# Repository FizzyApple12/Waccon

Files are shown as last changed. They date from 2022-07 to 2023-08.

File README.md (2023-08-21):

# Waccon

This repo is right now still a work in progress, nothing has been finalized and things will probably be broken, stay tuned as things are finalized though!

Simplified CAD Screenshot

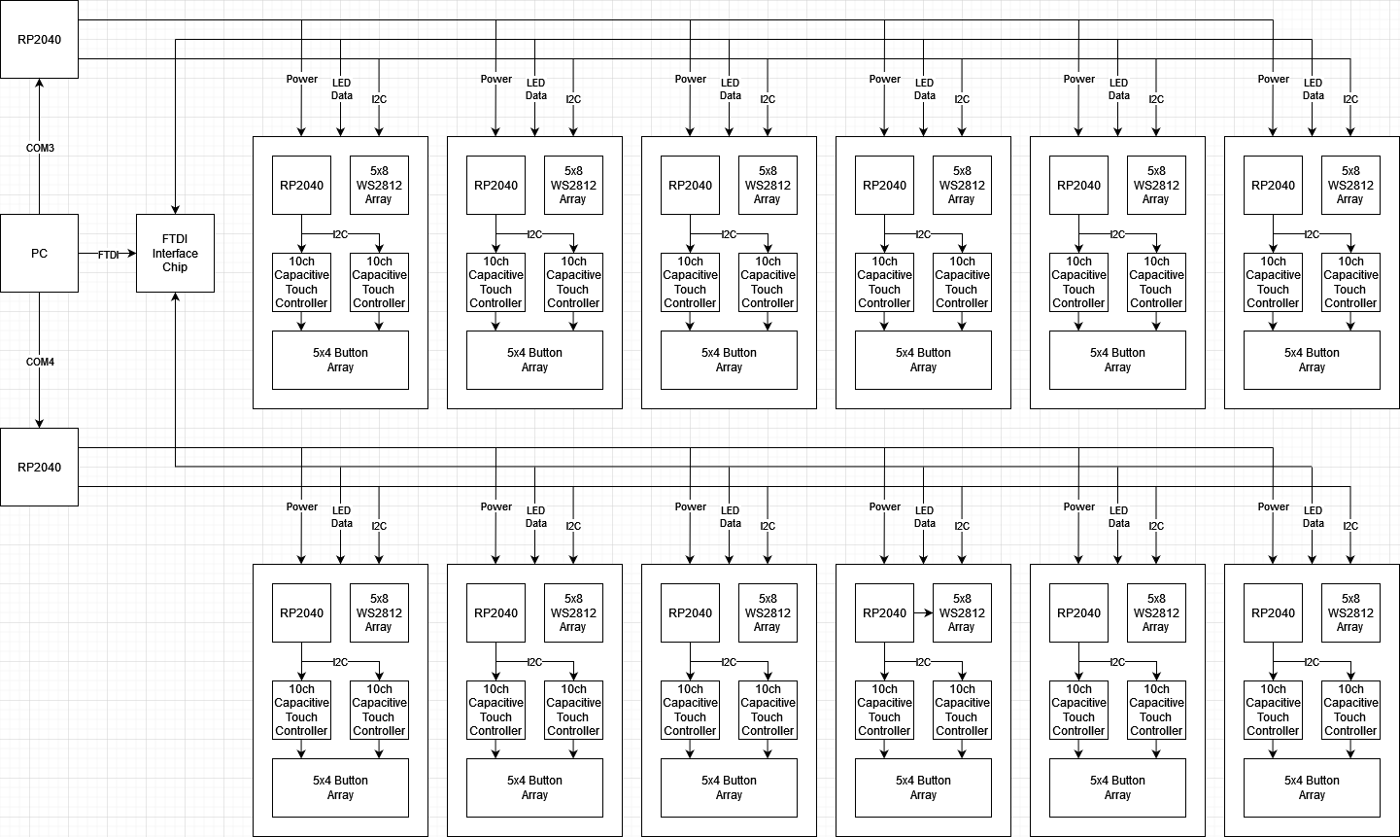
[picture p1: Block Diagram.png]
Controller Block Diagram


If you'd like to test out the current firmware on your own hardware, there are 2 github actions scripts for the Touch Panel firmware and the Protocol Translator firmware

The 6 Touch Panel firmware builds correspond to which position you want the Touch Panel to be in (1 being top, 6 being bottom)

The 4 Protocol Translator firmware builds correspond to if the translator is controlling the left or right of the controller and if you want to mirror Touch Panel 1's inputs to all 6 Touch Panels

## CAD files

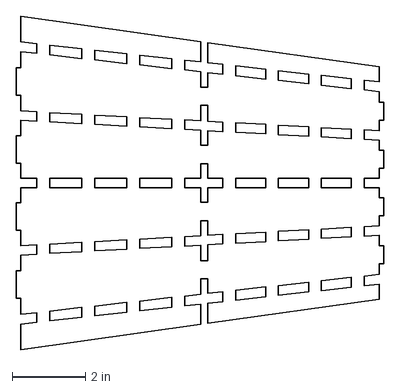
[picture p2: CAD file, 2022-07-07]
WaccaTouchPanel-pcb/pcbBorder.dxf
10.0 x 9.10 in

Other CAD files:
Wacca Controller/Full Controller.iam
Wacca Controller/Half Ring/Half Ring.iam
Wacca Controller/Touch Segment/Back Plate.ipt
Wacca Controller/Touch Segment/Center Plate.ipt
Wacca Controller/Touch Segment/Front Plate.ipt
Wacca Controller/Touch Segment/Inner Bracket.ipt
Wacca Controller/Touch Segment/Joiner.ipt
Wacca Controller/Touch Segment/PCB.ipt
Wacca Controller/Touch Segment/SidePlate.ipt
Wacca Controller/Touch Segment/Touch Fifth.ipt
Wacca Controller/Touch Segment/Touch Segment.iam

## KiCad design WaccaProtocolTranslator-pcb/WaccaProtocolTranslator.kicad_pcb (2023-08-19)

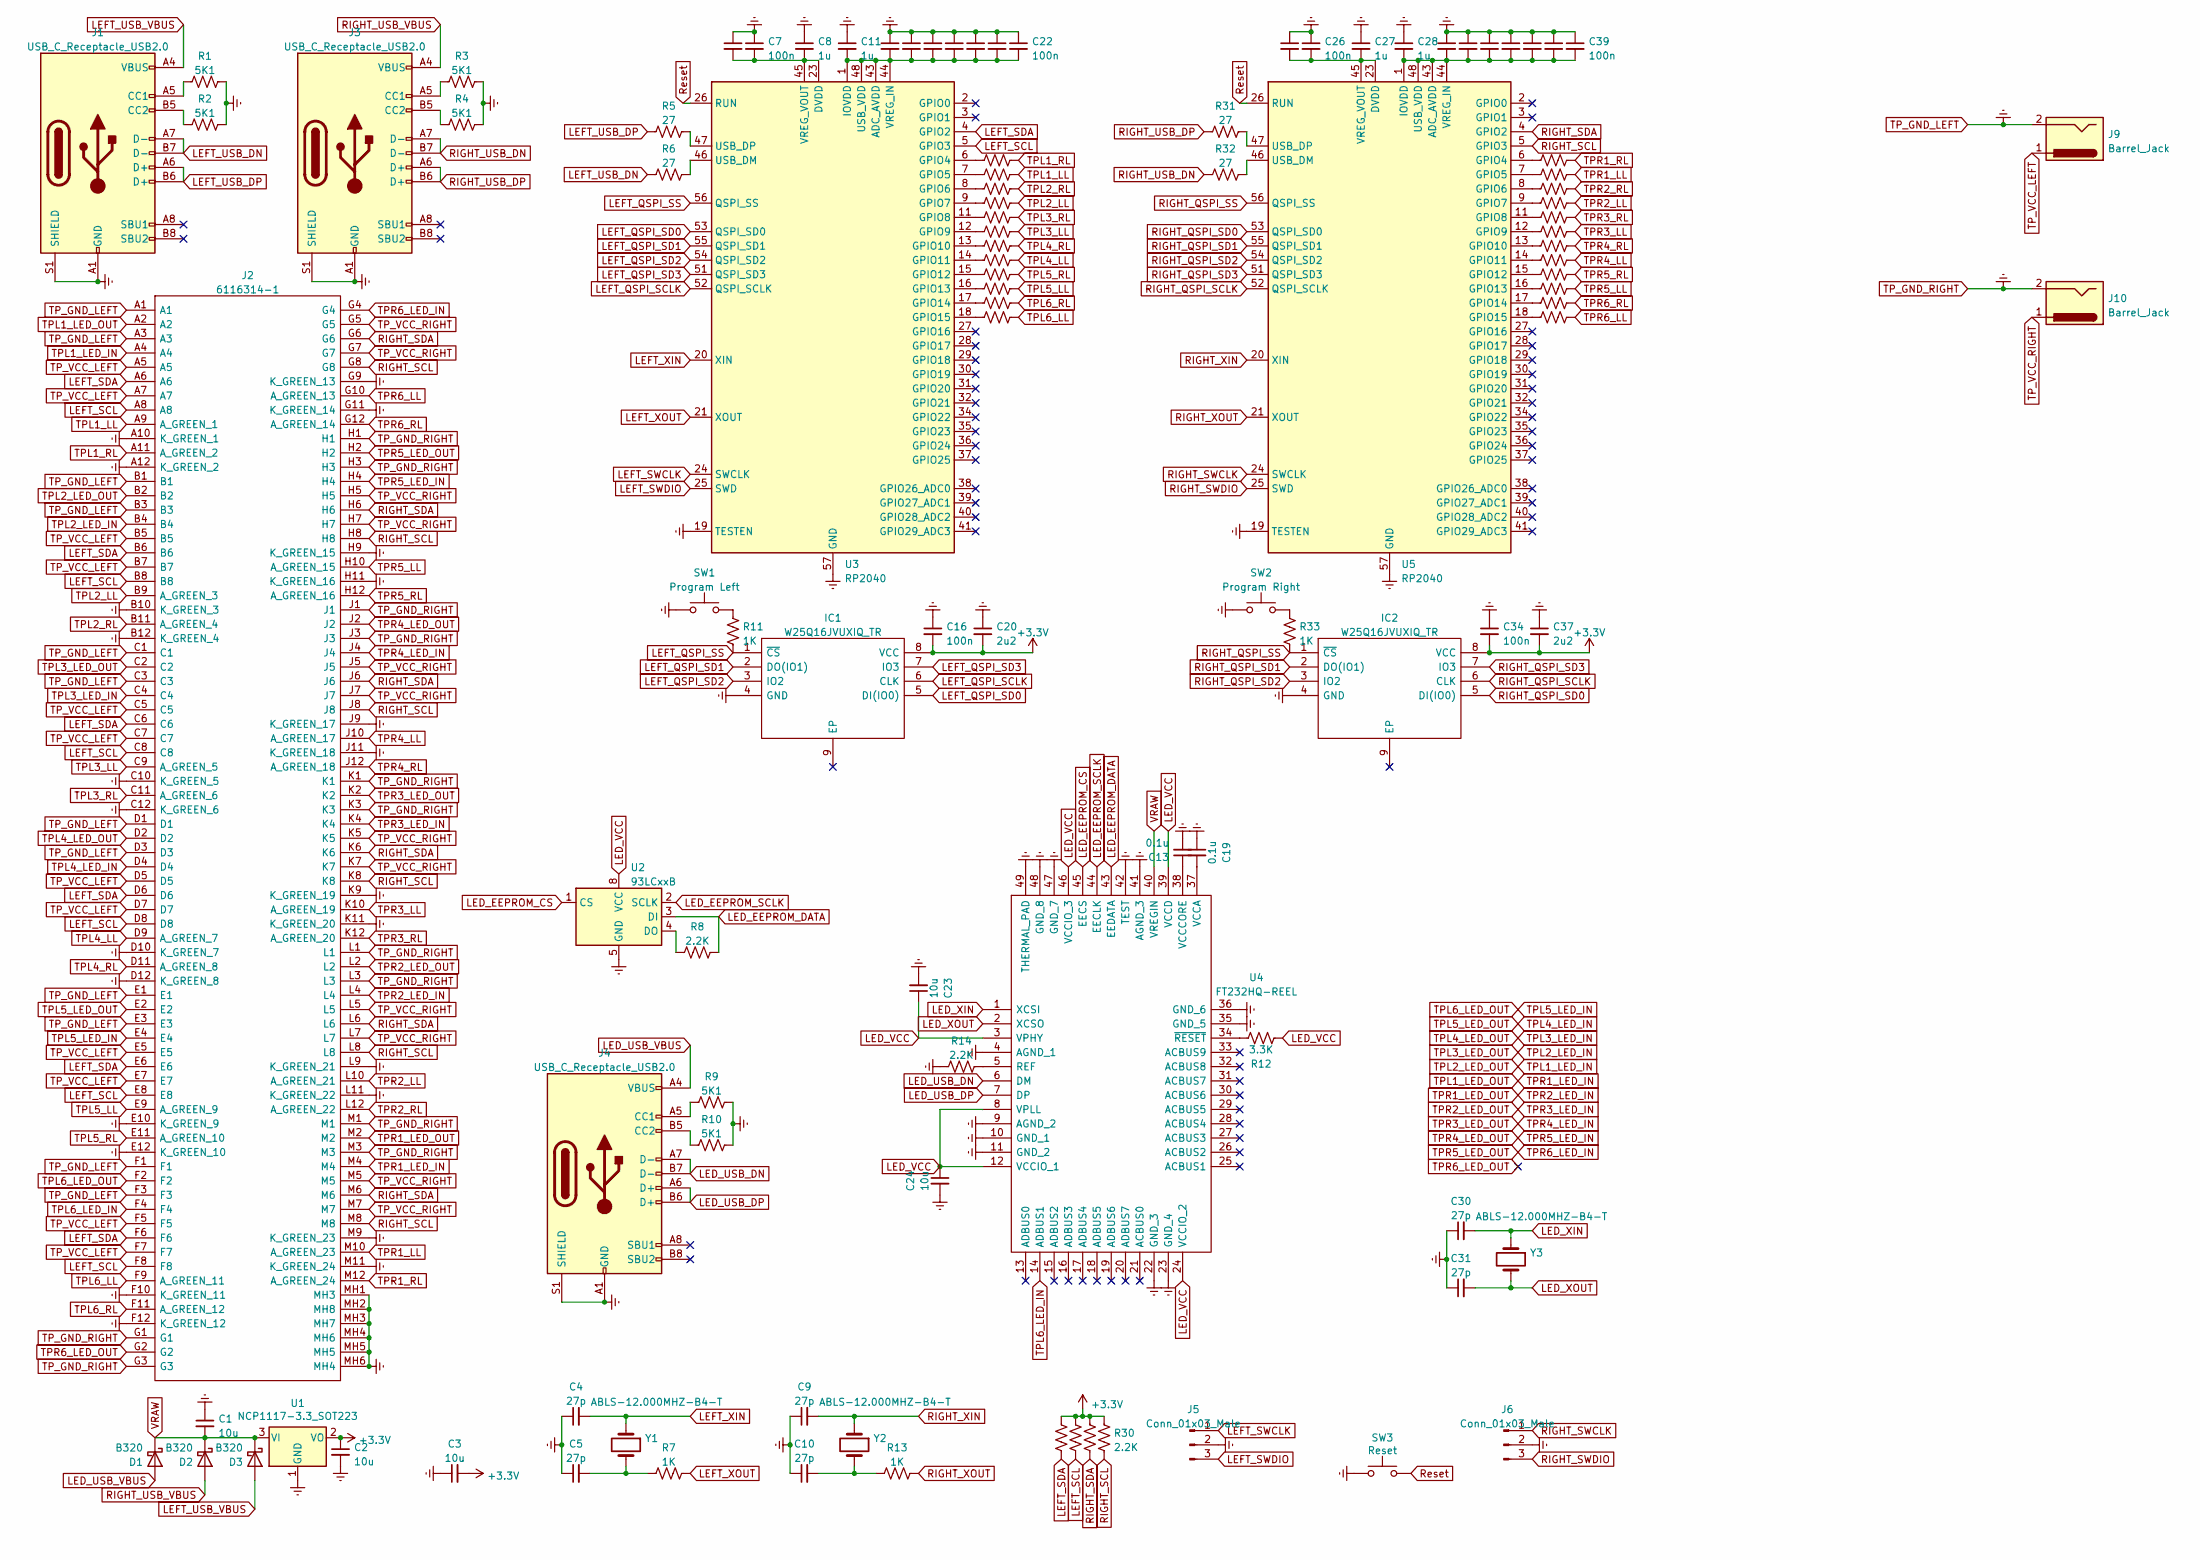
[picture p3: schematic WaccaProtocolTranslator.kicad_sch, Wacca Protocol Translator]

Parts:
C1, C2, C3, C23, C24: 10u; C_0402_1005Metric
C4, C5, C9, C10, C30, C31: 27p; C_0402_1005Metric
C6, C7, C12, C14, C15, C16, C17, C18, C21, C22, C25, C26, C29, C32, C33, C34, C35, C36, C38, C39: 100n; C_0402_1005Metric
C8, C11, C27, C28: 1u; C_0402_1005Metric
C13, C19: 0.1u; C_0402_1005Metric
C20, C37: 2u2; C_0402_1005Metric
D1, D2, D3: B320; D_SMC
IC1, IC2: W25Q16JVUXIQ_TR; SON50P300X200X60-9N; Manufacturer_Part_Number W25Q16JVUXIQ TR; Mouser Part Number 454-W25Q16JVUXIQTR
J1, J3, J4: USB_C_Receptacle_USB2.0; USB_C_Receptacle_Amphenol_12401548E4-2A
J2: 6116314-1; 61163141; Mouser Part Number 571-6116314-1
J5, J6: Conn_01x03_Male; PinHeader_1x03_P2.54mm_Vertical
J9, J10: Barrel_Jack; BarrelJack_CUI_PJ-063AH_Horizontal
R1, R2, R3, R4, R9, R10: 5K1; R_0402_1005Metric
R5, R6, R31, R32: 27; R_0402_1005Metric
R7, R11, R13, R33: 1K; R_0402_1005Metric
R8, R14, R27, R28, R29, R30: 2.2K; R_0402_1005Metric
R12: 3.3K; R_0402_1005Metric
R15, R16, R17, R18, R19, R20, R21, R22, R23, R24, R25, R26, R34, R35, R36, R37, R38, R39, R40, R41, R42, R43, R44, R45: 150; R_0402_1005Metric
SW1: Program Left; SW_SPST_B3U-1000P
SW2: Program Right; SW_SPST_B3U-1000P
SW3: Reset; SW_SPST_B3U-1000P
U1: NCP1117-3.3_SOT223; SOT-223-3_TabPin2
U2: 93LCxxB; SOP65P490X110-8N
U3, U5: RP2040; QFN-56-1EP_7x7mm_P0.4mm_EP3.2x3.2mm
U4: FT232HQ-REEL; QFN50P800X800X100-49N-D; Mouser Part Number 895-FT232HQ-REEL
Y1, Y2, Y3: ABLS-12.000MHZ-B4-T; Crystal_HC49-4H_Vertical

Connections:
+3.3V: C2.1, C3.2, C16.2, C20.2, C34.2, C37.2, IC1.8 (VCC), IC2.8 (VCC), R27.2, R28.2, R29.2, R30.2, U1.2 (VO)
LED_EEPROM_CS: U2.1 (CS), U4.45 (EECS)
LED_EEPROM_DATA: R8.2, U2.3 (DI), U4.43 (EEDATA)
LED_EEPROM_SCLK: U2.2 (SCLK), U4.44 (EECLK)
LED_USB_DN: J4.A7 (D-), J4.B7 (D-), U4.6 (DM)
LED_USB_DP: J4.A6 (D+), J4.B6 (D+), U4.7 (DP)
LED_USB_VBUS: D1.2 (A), J4.A4 (VBUS), J4.A9 (VBUS), J4.B4 (VBUS), J4.B9 (VBUS)
LED_VCC: C23.1, C24.1, R12.1, U2.8 (VCC), U4.3 (VPHY), U4.8 (VPLL), U4.12 (VCCIO_1), U4.24 (VCCIO_2), U4.39 (VCCD), U4.46 (VCCIO_3)
LED_XIN: C30.2, U4.1 (XCSI), Y3.1
LED_XOUT: C31.2, U4.2 (XCSO), Y3.2
LEFT_QSPI_SCLK: IC1.6 (CLK), U3.52 (QSPI_SCLK)
LEFT_QSPI_SD0: IC1.5 (DI(IO0)), U3.53 (QSPI_SD0)
LEFT_QSPI_SD1: IC1.2 (DO(IO1)), U3.55 (QSPI_SD1)
LEFT_QSPI_SD2: IC1.3 (IO2), U3.54 (QSPI_SD2)
LEFT_QSPI_SD3: IC1.7 (IO3), U3.51 (QSPI_SD3)
LEFT_QSPI_SS: IC1.1 (~CS), R11.2, U3.56 (QSPI_SS)
LEFT_SCL: J2.A8, J2.B8, J2.C8, J2.D8, J2.E8, J2.F8, R28.1, U3.5 (GPIO3)
LEFT_SDA: J2.A6, J2.B6, J2.C6, J2.D6, J2.E6, J2.F6, R27.1, U3.4 (GPIO2)
LEFT_SWCLK: J5.1, U3.24 (SWCLK)
LEFT_SWDIO: J5.3, U3.25 (SWD)
LEFT_USB_DN: J1.A7 (D-), J1.B7 (D-), R6.1
LEFT_USB_DP: J1.A6 (D+), J1.B6 (D+), R5.1
LEFT_USB_VBUS: D3.2 (A), J1.A4 (VBUS), J1.A9 (VBUS), J1.B4 (VBUS), J1.B9 (VBUS)
LEFT_XIN: C4.2, U3.20 (XIN), Y1.1
LEFT_XOUT: R7.2, U3.21 (XOUT)
unnamed: C5.2, R7.1, Y1.2
unnamed: C10.2, R13.1, Y2.2
unnamed: J1.A5 (CC1), R1.1
unnamed: J1.B5 (CC2), R2.1
unnamed: J3.A5 (CC1), R3.1
unnamed: J3.B5 (CC2), R4.1
unnamed: J4.A5 (CC1), R9.1
unnamed: J4.B5 (CC2), R10.1
unnamed: R11.1, SW1.2
unnamed: R33.1, SW2.2
unnamed: R8.1, U2.4 (DO)
unnamed: C11.2, C12.2, C14.2, C15.2, C17.2, C18.2, C21.2, C22.2, U3.1 (IOVDD), U3.10 (IOVDD), U3.22 (IOVDD), U3.33 (IOVDD), U3.42 (IOVDD), U3.43 (ADC_AVDD), U3.44 (VREG_IN), U3.48 (USB_VDD), U3.49 (IOVDD)
unnamed: R16.1, U3.6 (GPIO4)
unnamed: R15.1, U3.7 (GPIO5)
unnamed: R18.1, U3.8 (GPIO6)
unnamed: R17.1, U3.9 (GPIO7)
unnamed: R20.1, U3.11 (GPIO8)
unnamed: R19.1, U3.12 (GPIO9)
unnamed: R22.1, U3.13 (GPIO10)
unnamed: R21.1, U3.14 (GPIO11)
unnamed: R24.1, U3.15 (GPIO12)
unnamed: R23.1, U3.16 (GPIO13)
unnamed: R26.1, U3.17 (GPIO14)
unnamed: R25.1, U3.18 (GPIO15)
unnamed: R6.2, U3.46 (USB_DM)
unnamed: R5.2, U3.47 (USB_DP)
unnamed: C6.2, C7.2, C8.2, U3.23 (DVDD), U3.45 (VREG_VOUT), U3.50 (DVDD)
unnamed: R14.2, U4.5 (REF)
unnamed: C19.2, U4.37 (VCCA)
unnamed: C13.1, U4.38 (VCCCORE)
unnamed: R12.2, U4.34 (~RESET)
unnamed: C28.2, C29.2, C32.2, C33.2, C35.2, C36.2, C38.2, C39.2, U5.1 (IOVDD), U5.10 (IOVDD), U5.22 (IOVDD), U5.33 (IOVDD), U5.42 (IOVDD), U5.43 (ADC_AVDD), U5.44 (VREG_IN), U5.48 (USB_VDD), U5.49 (IOVDD)
unnamed: R35.1, U5.6 (GPIO4)
unnamed: R34.1, U5.7 (GPIO5)
unnamed: R37.1, U5.8 (GPIO6)
unnamed: R36.1, U5.9 (GPIO7)
unnamed: R39.1, U5.11 (GPIO8)
unnamed: R38.1, U5.12 (GPIO9)
unnamed: R41.1, U5.13 (GPIO10)
unnamed: R40.1, U5.14 (GPIO11)
unnamed: R43.1, U5.15 (GPIO12)
unnamed: R42.1, U5.16 (GPIO13)
unnamed: R45.1, U5.17 (GPIO14)
unnamed: R44.1, U5.18 (GPIO15)
unnamed: R32.2, U5.46 (USB_DM)
unnamed: R31.2, U5.47 (USB_DP)
unnamed: C25.2, C26.2, C27.2, U5.23 (DVDD), U5.45 (VREG_VOUT), U5.50 (DVDD)
RIGHT_QSPI_SCLK: IC2.6 (CLK), U5.52 (QSPI_SCLK)
RIGHT_QSPI_SD0: IC2.5 (DI(IO0)), U5.53 (QSPI_SD0)
RIGHT_QSPI_SD1: IC2.2 (DO(IO1)), U5.55 (QSPI_SD1)
RIGHT_QSPI_SD2: IC2.3 (IO2), U5.54 (QSPI_SD2)
RIGHT_QSPI_SD3: IC2.7 (IO3), U5.51 (QSPI_SD3)
RIGHT_QSPI_SS: IC2.1 (~CS), R33.2, U5.56 (QSPI_SS)
RIGHT_SCL: J2.G8, J2.H8, J2.J8, J2.K8, J2.L8, J2.M8, R30.1, U5.5 (GPIO3)
RIGHT_SDA: J2.G6, J2.H6, J2.J6, J2.K6, J2.L6, J2.M6, R29.1, U5.4 (GPIO2)
RIGHT_SWCLK: J6.1, U5.24 (SWCLK)
RIGHT_SWDIO: J6.3, U5.25 (SWD)
RIGHT_USB_DN: J3.A7 (D-), J3.B7 (D-), R32.1
RIGHT_USB_DP: J3.A6 (D+), J3.B6 (D+), R31.1
RIGHT_USB_VBUS: D2.2 (A), J3.A4 (VBUS), J3.A9 (VBUS), J3.B4 (VBUS), J3.B9 (VBUS)
RIGHT_XIN: C9.2, U5.20 (XIN), Y2.1
RIGHT_XOUT: R13.2, U5.21 (XOUT)
Reset: SW3.2, U3.26 (RUN), U5.26 (RUN)
TPL1_LED_IN: J2.A4, J2.B2
TPL1_LED_OUT: J2.A2, J2.M4
TPL1_LL: J2.A9 (A_GREEN_1), R15.2
TPL1_RL: J2.A11 (A_GREEN_2), R16.2
TPL2_LED_IN: J2.B4, J2.C2
TPL2_LL: J2.B9 (A_GREEN_3), R17.2
TPL2_RL: J2.B11 (A_GREEN_4), R18.2
TPL3_LED_IN: J2.C4, J2.D2
TPL3_LL: J2.C9 (A_GREEN_5), R19.2
TPL3_RL: J2.C11 (A_GREEN_6), R20.2
TPL4_LED_IN: J2.D4, J2.E2
TPL4_LL: J2.D9 (A_GREEN_7), R21.2
TPL4_RL: J2.D11 (A_GREEN_8), R22.2
TPL5_LED_IN: J2.E4, J2.F2
TPL5_LL: J2.E9 (A_GREEN_9), R23.2
TPL5_RL: J2.E11 (A_GREEN_10), R24.2
TPL6_LED_IN: J2.F4, U4.14 (ADBUS1)
TPL6_LL: J2.F9 (A_GREEN_11), R25.2
TPL6_RL: J2.F11 (A_GREEN_12), R26.2
TPR1_LED_OUT: J2.L4, J2.M2
TPR1_LL: J2.M10 (A_GREEN_23), R34.2
TPR1_RL: J2.M12 (A_GREEN_24), R35.2
TPR2_LED_OUT: J2.K4, J2.L2
TPR2_LL: J2.L10 (A_GREEN_21), R36.2
TPR2_RL: J2.L12 (A_GREEN_22), R37.2
TPR3_LED_OUT: J2.J4, J2.K2
TPR3_LL: J2.K10 (A_GREEN_19), R38.2
TPR3_RL: J2.K12 (A_GREEN_20), R39.2
TPR4_LED_OUT: J2.H4, J2.J2
TPR4_LL: J2.J10 (A_GREEN_17), R40.2
TPR4_RL: J2.J12 (A_GREEN_18), R41.2
TPR5_LED_OUT: J2.G4, J2.H2
TPR5_LL: J2.H10 (A_GREEN_15), R42.2
TPR5_RL: J2.H12 (A_GREEN_16), R43.2
TPR6_LED_OUT: J2.G2
TPR6_LL: J2.G10 (A_GREEN_13), R44.2
TPR6_RL: J2.G12 (A_GREEN_14), R45.2
TP_GND_LEFT: C1.1, C2.2, C3.1, C4.1, C5.1, C6.1, C7.1, C8.1, C9.1, C10.1, C11.1, C12.1, C13.2, C14.1, C15.1, C16.1, C17.1, C18.1, C19.1, C20.1, C21.1, C22.1, C23.2, C24.2, C25.1, C26.1, C27.1, C28.1, C29.1, C30.1, C31.1, C32.1, C33.1, C34.1, C35.1, C36.1, C37.1, C38.1, C39.1, IC1.4 (GND), IC2.4 (GND), J1.A1 (GND), J1.A12 (GND), J1.B1 (GND), J1.B12 (GND), J1.S1 (SHIELD), J2.A1, J2.A3, J2.A10 (K_GREEN_1), J2.A12 (K_GREEN_2), J2.B1, J2.B3, J2.B10 (K_GREEN_3), J2.B12 (K_GREEN_4), J2.C1, J2.C3, J2.C10 (K_GREEN_5), J2.C12 (K_GREEN_6), J2.D1, J2.D3, J2.D10 (K_GREEN_7), J2.D12 (K_GREEN_8), J2.E1, J2.E3, J2.E10 (K_GREEN_9), J2.E12 (K_GREEN_10), J2.F1, J2.F3, J2.F10 (K_GREEN_11), J2.F12 (K_GREEN_12), J2.G1, J2.G3, J2.G9 (K_GREEN_13), J2.G11 (K_GREEN_14), J2.H1, J2.H3, J2.H9 (K_GREEN_15), J2.H11 (K_GREEN_16), J2.J1, J2.J3, J2.J9 (K_GREEN_17), J2.J11 (K_GREEN_18), J2.K1, J2.K3, J2.K9 (K_GREEN_19), J2.K11 (K_GREEN_20), J2.L1, J2.L3, J2.L9 (K_GREEN_21), J2.L11 (K_GREEN_22), J2.M1, J2.M3, J2.M9 (K_GREEN_23), J2.M11 (K_GREEN_24), J2.MH1 (MH3), J2.MH2 (MH8), J2.MH3 (MH7), J2.MH4 (MH6), J2.MH5, J2.MH6 (MH4), J3.A1 (GND), J3.A12 (GND), J3.B1 (GND), J3.B12 (GND), J3.S1 (SHIELD), J4.A1 (GND), J4.A12 (GND), J4.B1 (GND), J4.B12 (GND), J4.S1 (SHIELD), J5.2, J6.2, J9.2, J10.2, R1.2, R2.2, R3.2, R4.2, R9.2, R10.2, R14.1, SW1.1, SW2.1, SW3.1, U1.1 (GND), U2.5 (GND), U3.19 (TESTEN), U3.57 (GND), U4.4 (AGND_1), U4.9 (AGND_2), U4.10 (GND_1), U4.11 (GND_2), U4.22 (GND_3), U4.23 (GND_4), U4.35 (GND_5), U4.36 (GND_6), U4.41 (AGND_3), U4.42 (TEST), U4.47 (GND_7), U4.48 (GND_8), U4.49 (THERMAL_PAD), U5.19 (TESTEN), U5.57 (GND)
TP_VCC_LEFT: J2.A5, J2.A7, J2.B5, J2.B7, J2.C5, J2.C7, J2.D5, J2.D7, J2.E5, J2.E7, J2.F5, J2.F7, J9.1
TP_VCC_RIGHT: J2.G5, J2.G7, J2.H5, J2.H7, J2.J5, J2.J7, J2.K5, J2.K7, J2.L5, J2.L7, J2.M5, J2.M7, J10.1
VRAW: C1.2, D1.1 (K), D2.1 (K), D3.1 (K), U1.3 (VI), U4.40 (VREGIN)

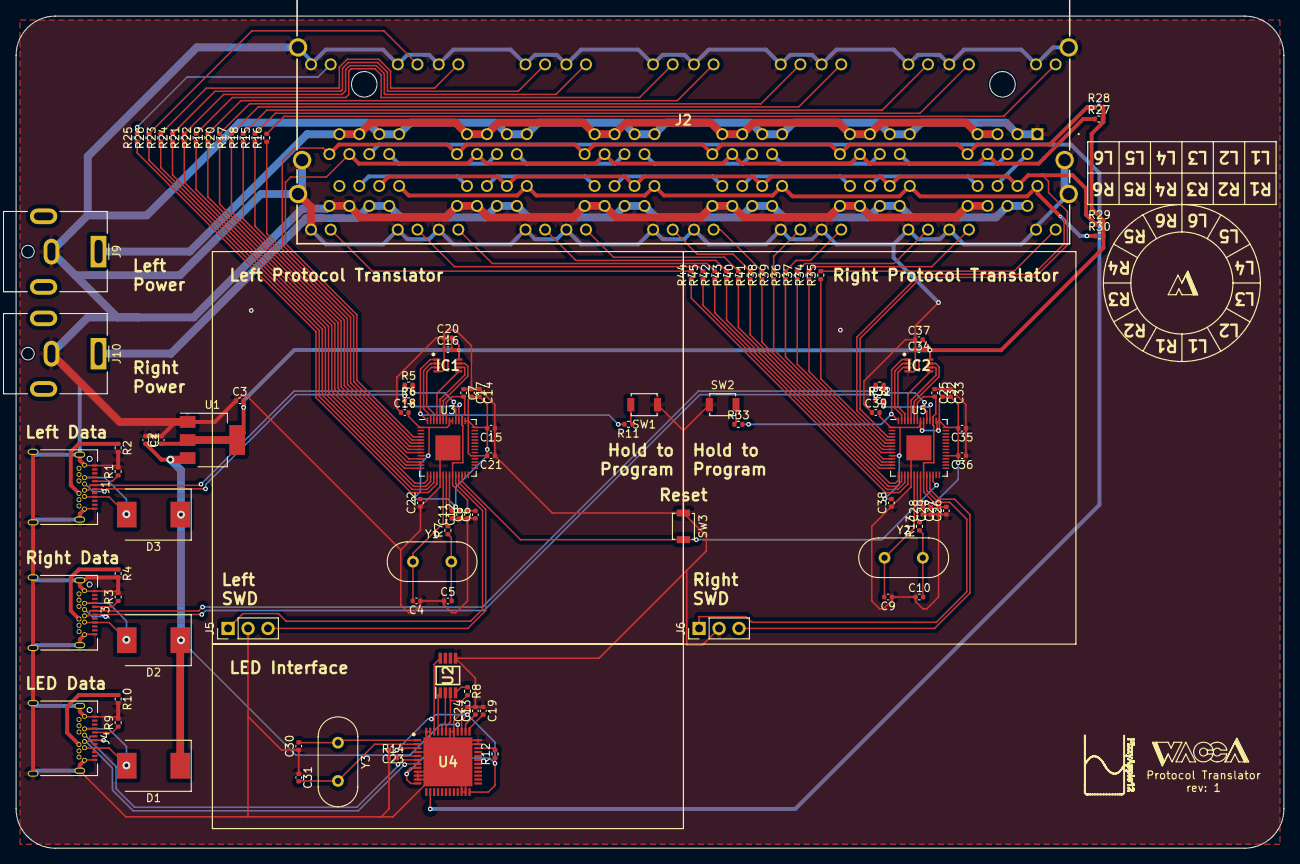
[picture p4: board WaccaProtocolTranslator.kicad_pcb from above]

Board: 2 copper layers, 161.5 x 106.0 mm, 108 parts (0 on the bottom side), 128 nets.

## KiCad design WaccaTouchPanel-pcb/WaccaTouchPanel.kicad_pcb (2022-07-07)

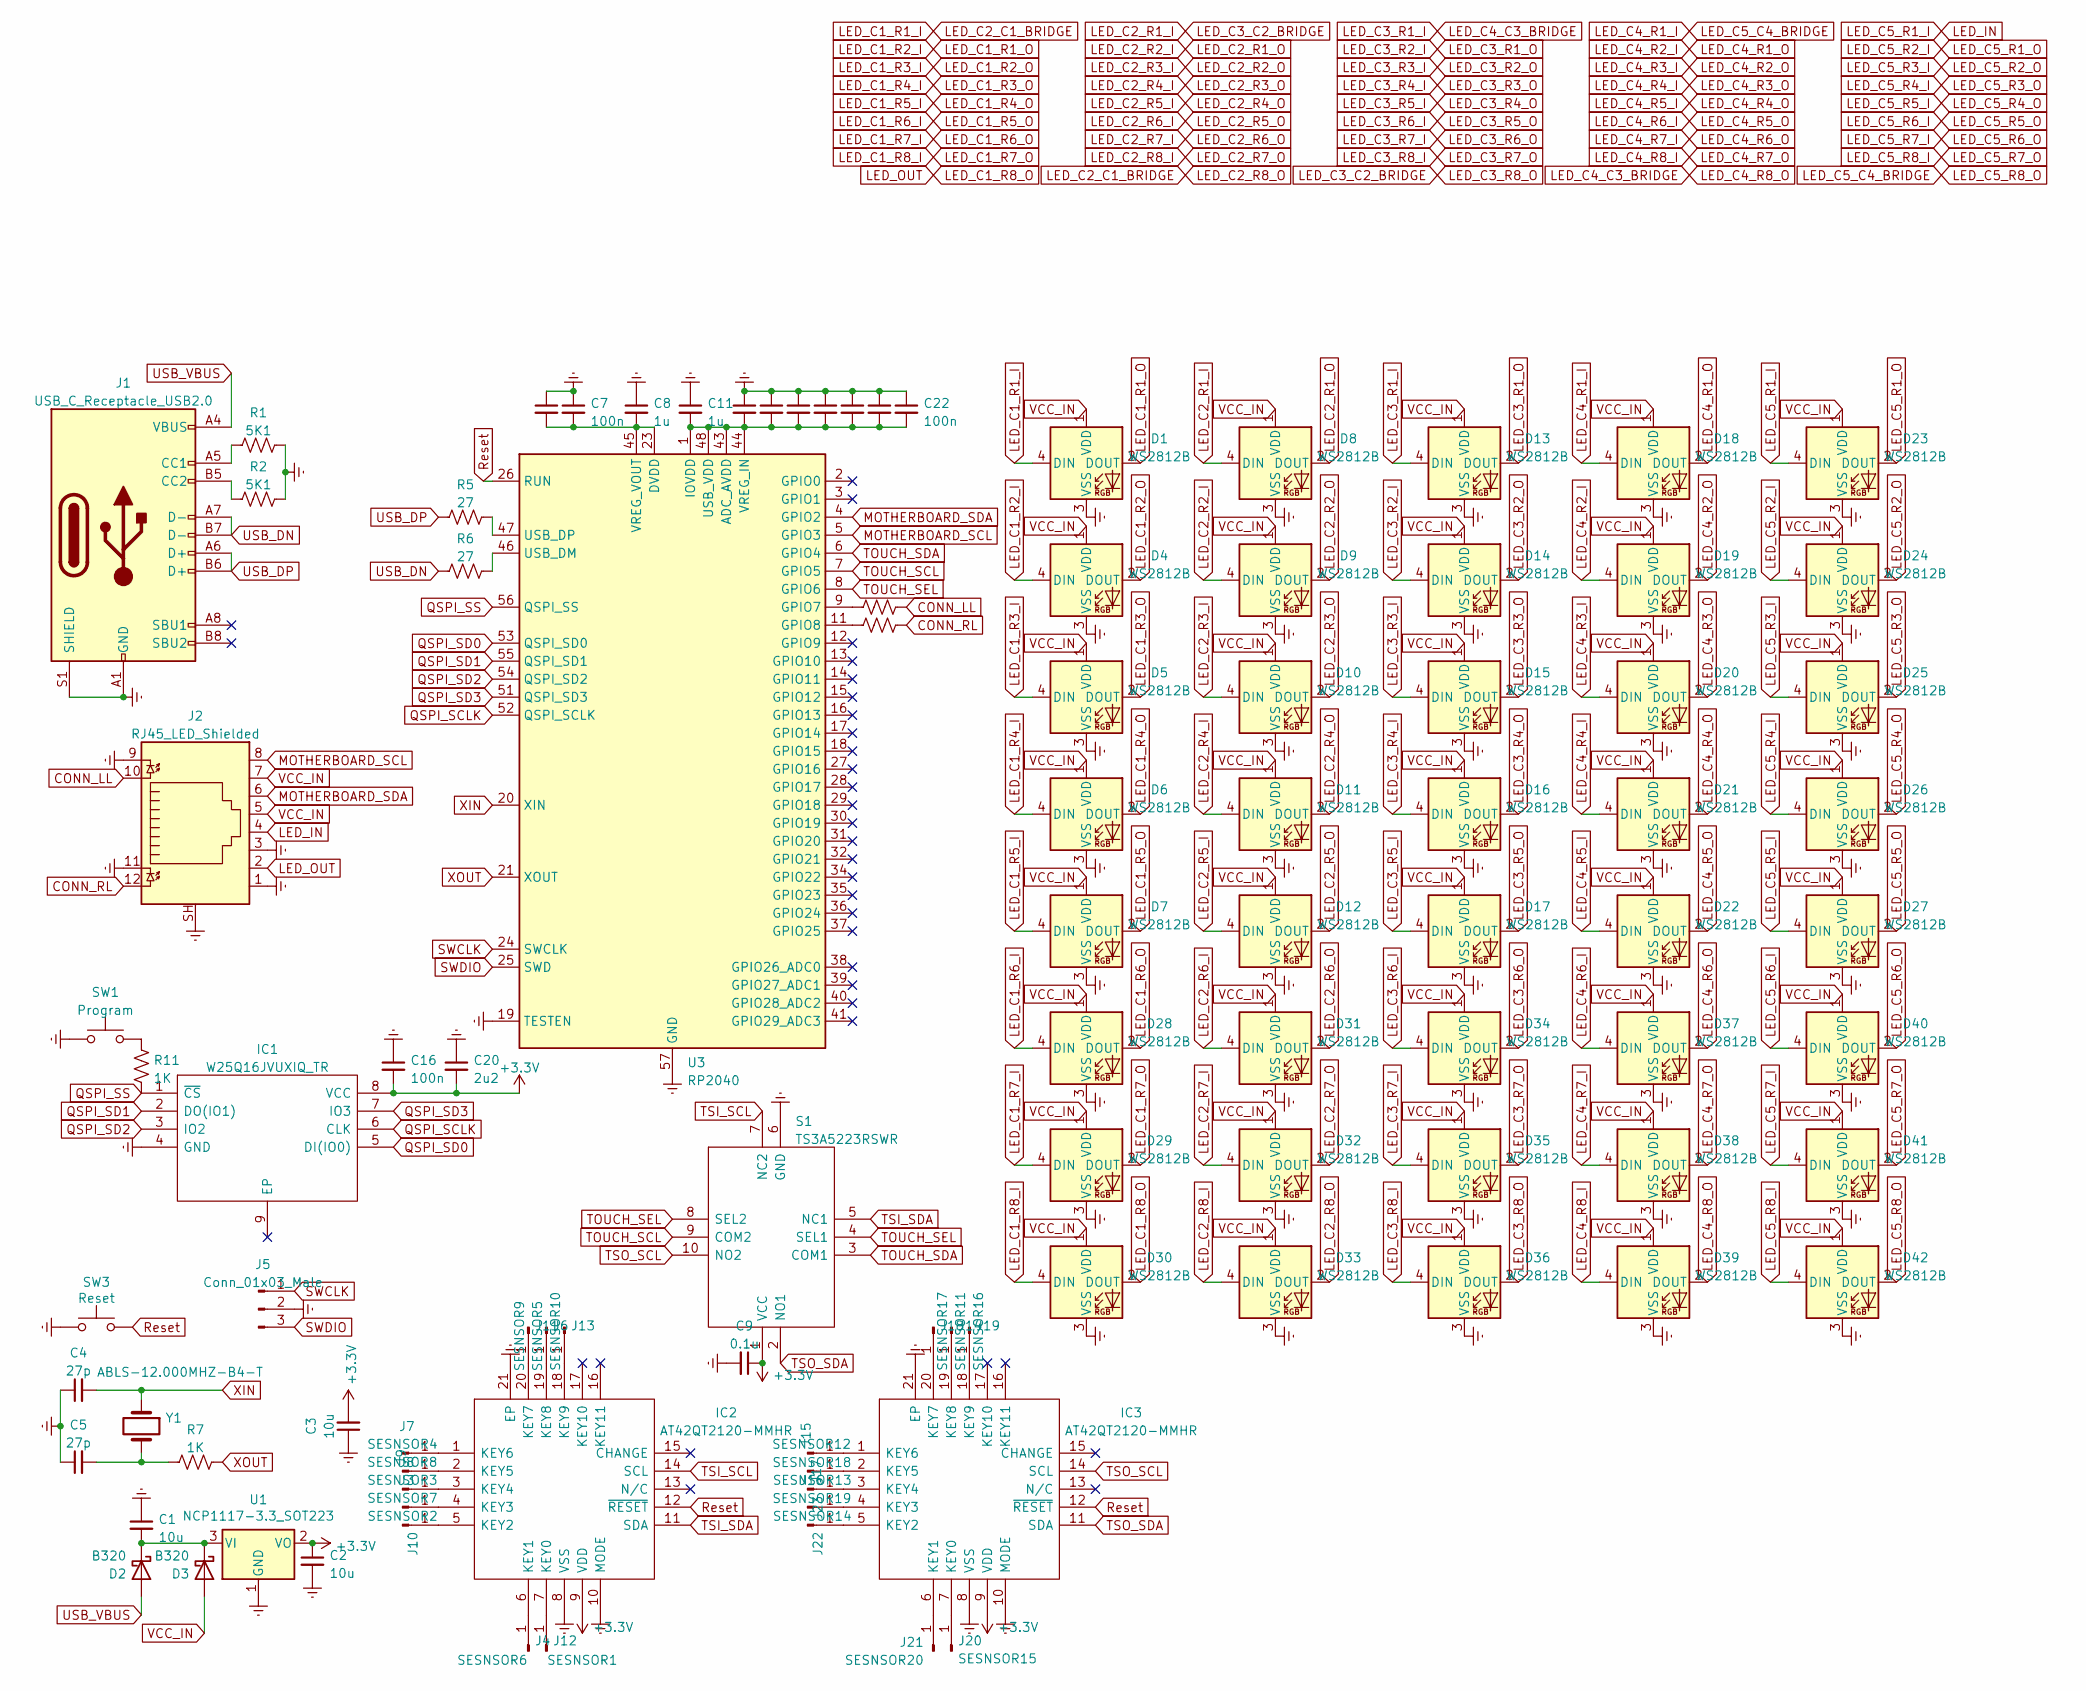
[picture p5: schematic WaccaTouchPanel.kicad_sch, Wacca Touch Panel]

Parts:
C1, C2, C3: 10u; C_0402_1005Metric
C4, C5: 27p; C_0402_1005Metric
C6, C7, C12, C14, C15, C16, C17, C18, C21, C22: 100n; C_0402_1005Metric
C8, C11: 1u; C_0402_1005Metric
C9: 0.1u; C_0402_1005Metric
C20: 2u2; C_0402_1005Metric
D1, D4, D5, D6, D7, D8, D9, D10, D11, D12, D13, D14, D15, D16, D17, D18, D19, D20, D21, D22, D23, D24, D25, D26, D27, D28, D29, D30, D31, D32, D33, D34, D35, D36, D37, D38, D39, D40, D41, D42: WS2812B; LED_WS2812B_PLCC4_5.0x5.0mm_P3.2mm
D2, D3: B320; D_SMC
IC1: W25Q16JVUXIQ_TR; SON50P300X200X60-9N; Manufacturer_Part_Number W25Q16JVUXIQ TR; Mouser Part Number 454-W25Q16JVUXIQTR
IC2, IC3: AT42QT2120-MMHR; QFN45P300X300X85-21N; Mouser Part Number 556-AT42QT2120-MMHR
J1: USB_C_Receptacle_USB2.0; USB_C_Receptacle_Amphenol_12401548E4-2A
J2: RJ45_LED_Shielded; RJ45_Amphenol_RJHSE538X
J3: SESNSOR7; PinHeader_1x01_P2.54mm_Vertical
J4: SESNSOR6; PinHeader_1x01_P2.54mm_Vertical
J5: Conn_01x03_Male; PinHeader_1x03_P2.54mm_Vertical
J6: SESNSOR5; PinHeader_1x01_P2.54mm_Vertical
J7: SESNSOR4; PinHeader_1x01_P2.54mm_Vertical
J8: SESNSOR3; PinHeader_1x01_P2.54mm_Vertical
J9: SESNSOR8; PinHeader_1x01_P2.54mm_Vertical
J10: SESNSOR2; PinHeader_1x01_P2.54mm_Vertical
J11: SESNSOR9; PinHeader_1x01_P2.54mm_Vertical
J12: SESNSOR1; PinHeader_1x01_P2.54mm_Vertical
J13: SESNSOR10; PinHeader_1x01_P2.54mm_Vertical
J14: SESNSOR11; PinHeader_1x01_P2.54mm_Vertical
J15: SESNSOR12; PinHeader_1x01_P2.54mm_Vertical
J16: SESNSOR19; PinHeader_1x01_P2.54mm_Vertical
J17: SESNSOR18; PinHeader_1x01_P2.54mm_Vertical
J18: SESNSOR17; PinHeader_1x01_P2.54mm_Vertical
J19: SESNSOR16; PinHeader_1x01_P2.54mm_Vertical
J20: SESNSOR15; PinHeader_1x01_P2.54mm_Vertical
J21: SESNSOR20; PinHeader_1x01_P2.54mm_Vertical
J22: SESNSOR14; PinHeader_1x01_P2.54mm_Vertical
J23: SESNSOR13; PinHeader_1x01_P2.54mm_Vertical
R1, R2: 5K1; R_0402_1005Metric
R5, R6: 27; R_0402_1005Metric
R7, R11: 1K; R_0402_1005Metric
R15, R16: 150; R_0402_1005Metric
S1: TS3A5223RSWR; RSW_RPUQFNN10_; Mouser Part Number 595-TS3A5223RSWR
SW1: Program; SW_SPST_B3U-1000P
SW3: Reset; SW_SPST_B3U-1000P
U1: NCP1117-3.3_SOT223; SOT-223-3_TabPin2
U3: RP2040; QFN-56-1EP_7x7mm_P0.4mm_EP3.2x3.2mm
Y1: ABLS-12.000MHZ-B4-T; Crystal_HC49-4H_Vertical

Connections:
+3.3V: C2.1, C3.2, C9.1, C16.2, C20.2, IC1.8 (VCC), IC2.9 (VDD), IC3.9 (VDD), S1.1 (VCC), U1.2 (VO)
CONN_LL: J2.10, R16.2
CONN_RL: J2.12, R15.2
Earth: C1.1, C2.2, C3.1, C4.1, C5.1, C6.1, C7.1, C8.1, C9.2, C11.1, C12.1, C14.1, C15.1, C16.1, C17.1, C18.1, C20.1, C21.1, C22.1, D1.3 (VSS), D4.3 (VSS), D5.3 (VSS), D6.3 (VSS), D7.3 (VSS), D8.3 (VSS), D9.3 (VSS), D10.3 (VSS), D11.3 (VSS), D12.3 (VSS), D13.3 (VSS), D14.3 (VSS), D15.3 (VSS), D16.3 (VSS), D17.3 (VSS), D18.3 (VSS), D19.3 (VSS), D20.3 (VSS), D21.3 (VSS), D22.3 (VSS), D23.3 (VSS), D24.3 (VSS), D25.3 (VSS), D26.3 (VSS), D27.3 (VSS), D28.3 (VSS), D29.3 (VSS), D30.3 (VSS), D31.3 (VSS), D32.3 (VSS), D33.3 (VSS), D34.3 (VSS), D35.3 (VSS), D36.3 (VSS), D37.3 (VSS), D38.3 (VSS), D39.3 (VSS), D40.3 (VSS), D41.3 (VSS), D42.3 (VSS), IC1.4 (GND), IC2.8 (VSS), IC2.10 (MODE), IC2.21 (EP), IC3.8 (VSS), IC3.10 (MODE), IC3.21 (EP), J1.A1 (GND), J1.A12 (GND), J1.B1 (GND), J1.B12 (GND), J1.S1 (SHIELD), J2.1, J2.3, J2.9, J2.11, J2.SH, J5.2, R1.2, R2.2, S1.6 (GND), SW1.1, SW3.1, U1.1 (GND), U3.19 (TESTEN), U3.57 (GND)
LED_C1_R1_I: D1.4 (DIN), D33.2 (DOUT)
LED_C1_R1_O: D1.2 (DOUT), D4.4 (DIN)
LED_C1_R2_O: D4.2 (DOUT), D5.4 (DIN)
LED_C1_R3_O: D5.2 (DOUT), D6.4 (DIN)
LED_C1_R4_O: D6.2 (DOUT), D7.4 (DIN)
LED_C1_R5_O: D7.2 (DOUT), D28.4 (DIN)
LED_C1_R6_O: D28.2 (DOUT), D29.4 (DIN)
LED_C1_R7_O: D29.2 (DOUT), D30.4 (DIN)
LED_C1_R8_O: D30.2 (DOUT), J2.2
LED_C2_R1_O: D8.2 (DOUT), D9.4 (DIN)
LED_C2_R2_O: D9.2 (DOUT), D10.4 (DIN)
LED_C2_R3_O: D10.2 (DOUT), D11.4 (DIN)
LED_C2_R4_O: D11.2 (DOUT), D12.4 (DIN)
LED_C2_R6_I: D12.2 (DOUT), D31.4 (DIN)
LED_C2_R6_O: D31.2 (DOUT), D32.4 (DIN)
LED_C2_R7_O: D32.2 (DOUT), D33.4 (DIN)
LED_C3_R1_I: D13.4 (DIN), D39.2 (DOUT)
LED_C3_R1_O: D13.2 (DOUT), D14.4 (DIN)
LED_C3_R2_O: D14.2 (DOUT), D15.4 (DIN)
LED_C3_R3_O: D15.2 (DOUT), D16.4 (DIN)
LED_C3_R4_O: D16.2 (DOUT), D17.4 (DIN)
LED_C3_R5_O: D17.2 (DOUT), D34.4 (DIN)
LED_C3_R6_O: D34.2 (DOUT), D35.4 (DIN)
LED_C3_R7_O: D35.2 (DOUT), D36.4 (DIN)
LED_C3_R8_O: D8.4 (DIN), D36.2 (DOUT)
LED_C4_R2_I: D18.2 (DOUT), D19.4 (DIN)
LED_C4_R3_I: D19.2 (DOUT), D20.4 (DIN)
LED_C4_R4_I: D20.2 (DOUT), D21.4 (DIN)
LED_C4_R5_I: D21.2 (DOUT), D22.4 (DIN)
LED_C4_R5_O: D22.2 (DOUT), D37.4 (DIN)
LED_C4_R6_O: D37.2 (DOUT), D38.4 (DIN)
LED_C4_R7_O: D38.2 (DOUT), D39.4 (DIN)
LED_C5_R1_I: D23.4 (DIN), J2.4
LED_C5_R2_I: D23.2 (DOUT), D24.4 (DIN)
LED_C5_R3_I: D24.2 (DOUT), D25.4 (DIN)
LED_C5_R4_I: D25.2 (DOUT), D26.4 (DIN)
LED_C5_R5_I: D26.2 (DOUT), D27.4 (DIN)
LED_C5_R5_O: D27.2 (DOUT), D40.4 (DIN)
LED_C5_R6_O: D40.2 (DOUT), D41.4 (DIN)
LED_C5_R7_O: D41.2 (DOUT), D42.4 (DIN)
LED_C5_R8_O: D18.4 (DIN), D42.2 (DOUT)
MOTHERBOARD_SCL: J2.8, U3.5 (GPIO3)
MOTHERBOARD_SDA: J2.6, U3.4 (GPIO2)
unnamed: C1.2, D2.1 (K), D3.1 (K), U1.3 (VI)
unnamed: C5.2, R7.1, Y1.2
unnamed: C6.2, C7.2, C8.2, U3.23 (DVDD), U3.45 (VREG_VOUT), U3.50 (DVDD)
unnamed: C11.2, C12.2, C14.2, C15.2, C17.2, C18.2, C21.2, C22.2, U3.1 (IOVDD), U3.10 (IOVDD), U3.22 (IOVDD), U3.33 (IOVDD), U3.42 (IOVDD), U3.43 (ADC_AVDD), U3.44 (VREG_IN), U3.48 (USB_VDD), U3.49 (IOVDD)
unnamed: IC2.1 (KEY6), J7.1
unnamed: IC2.2 (KEY5), J9.1
unnamed: IC2.3 (KEY4), J8.1
unnamed: IC2.4 (KEY3), J3.1
unnamed: IC2.5 (KEY2), J10.1
unnamed: IC2.6 (KEY1), J4.1
unnamed: IC2.7 (KEY0), J12.1
unnamed: IC2.18 (KEY9), J13.1
unnamed: IC2.19 (KEY8), J6.1
unnamed: IC2.20 (KEY7), J11.1
unnamed: IC3.1 (KEY6), J15.1
unnamed: IC3.2 (KEY5), J17.1
unnamed: IC3.3 (KEY4), J23.1
unnamed: IC3.4 (KEY3), J16.1
unnamed: IC3.5 (KEY2), J22.1
unnamed: IC3.6 (KEY1), J21.1
unnamed: IC3.7 (KEY0), J20.1
unnamed: IC3.18 (KEY9), J19.1
unnamed: IC3.19 (KEY8), J14.1
unnamed: IC3.20 (KEY7), J18.1
unnamed: J1.A5 (CC1), R1.1
unnamed: J1.B5 (CC2), R2.1
unnamed: R5.2, U3.47 (USB_DP)
unnamed: R6.2, U3.46 (USB_DM)
unnamed: R11.1, SW1.2
unnamed: R15.1, U3.11 (GPIO8)
unnamed: R16.1, U3.9 (GPIO7)
QSPI_SCLK: IC1.6 (CLK), U3.52 (QSPI_SCLK)
QSPI_SD0: IC1.5 (DI(IO0)), U3.53 (QSPI_SD0)
QSPI_SD1: IC1.2 (DO(IO1)), U3.55 (QSPI_SD1)
QSPI_SD2: IC1.3 (IO2), U3.54 (QSPI_SD2)
QSPI_SD3: IC1.7 (IO3), U3.51 (QSPI_SD3)
QSPI_SS: IC1.1 (~CS), R11.2, U3.56 (QSPI_SS)
Reset: IC2.12 (~RESET), IC3.12 (~RESET), SW3.2, U3.26 (RUN)
SWCLK: J5.1, U3.24 (SWCLK)
SWDIO: J5.3, U3.25 (SWD)
TOUCH_SCL: S1.9 (COM2), U3.7 (GPIO5)
TOUCH_SDA: S1.3 (COM1), U3.6 (GPIO4)
TOUCH_SEL: S1.4 (SEL1), S1.8 (SEL2), U3.8 (GPIO6)
TSI_SCL: IC2.14 (SCL), S1.7 (NC2)
TSI_SDA: IC2.11 (SDA), S1.5 (NC1)
TSO_SCL: IC3.14 (SCL), S1.10 (NO2)
TSO_SDA: IC3.11 (SDA), S1.2 (NO1)
USB_DN: J1.A7 (D-), J1.B7 (D-), R6.1
USB_DP: J1.A6 (D+), J1.B6 (D+), R5.1
USB_VBUS: D2.2 (A), J1.A4 (VBUS), J1.A9 (VBUS), J1.B4 (VBUS), J1.B9 (VBUS)
VCC_IN: D1.1 (VDD), D3.2 (A), D4.1 (VDD), D5.1 (VDD), D6.1 (VDD), D7.1 (VDD), D8.1 (VDD), D9.1 (VDD), D10.1 (VDD), D11.1 (VDD), D12.1 (VDD), D13.1 (VDD), D14.1 (VDD), D15.1 (VDD), D16.1 (VDD), D17.1 (VDD), D18.1 (VDD), D19.1 (VDD), D20.1 (VDD), D21.1 (VDD), D22.1 (VDD), D23.1 (VDD), D24.1 (VDD), D25.1 (VDD), D26.1 (VDD), D27.1 (VDD), D28.1 (VDD), D29.1 (VDD), D30.1 (VDD), D31.1 (VDD), D32.1 (VDD), D33.1 (VDD), D34.1 (VDD), D35.1 (VDD), D36.1 (VDD), D37.1 (VDD), D38.1 (VDD), D39.1 (VDD), D40.1 (VDD), D41.1 (VDD), D42.1 (VDD), J2.5, J2.7
XIN: C4.2, U3.20 (XIN), Y1.1
XOUT: R7.2, U3.21 (XOUT)

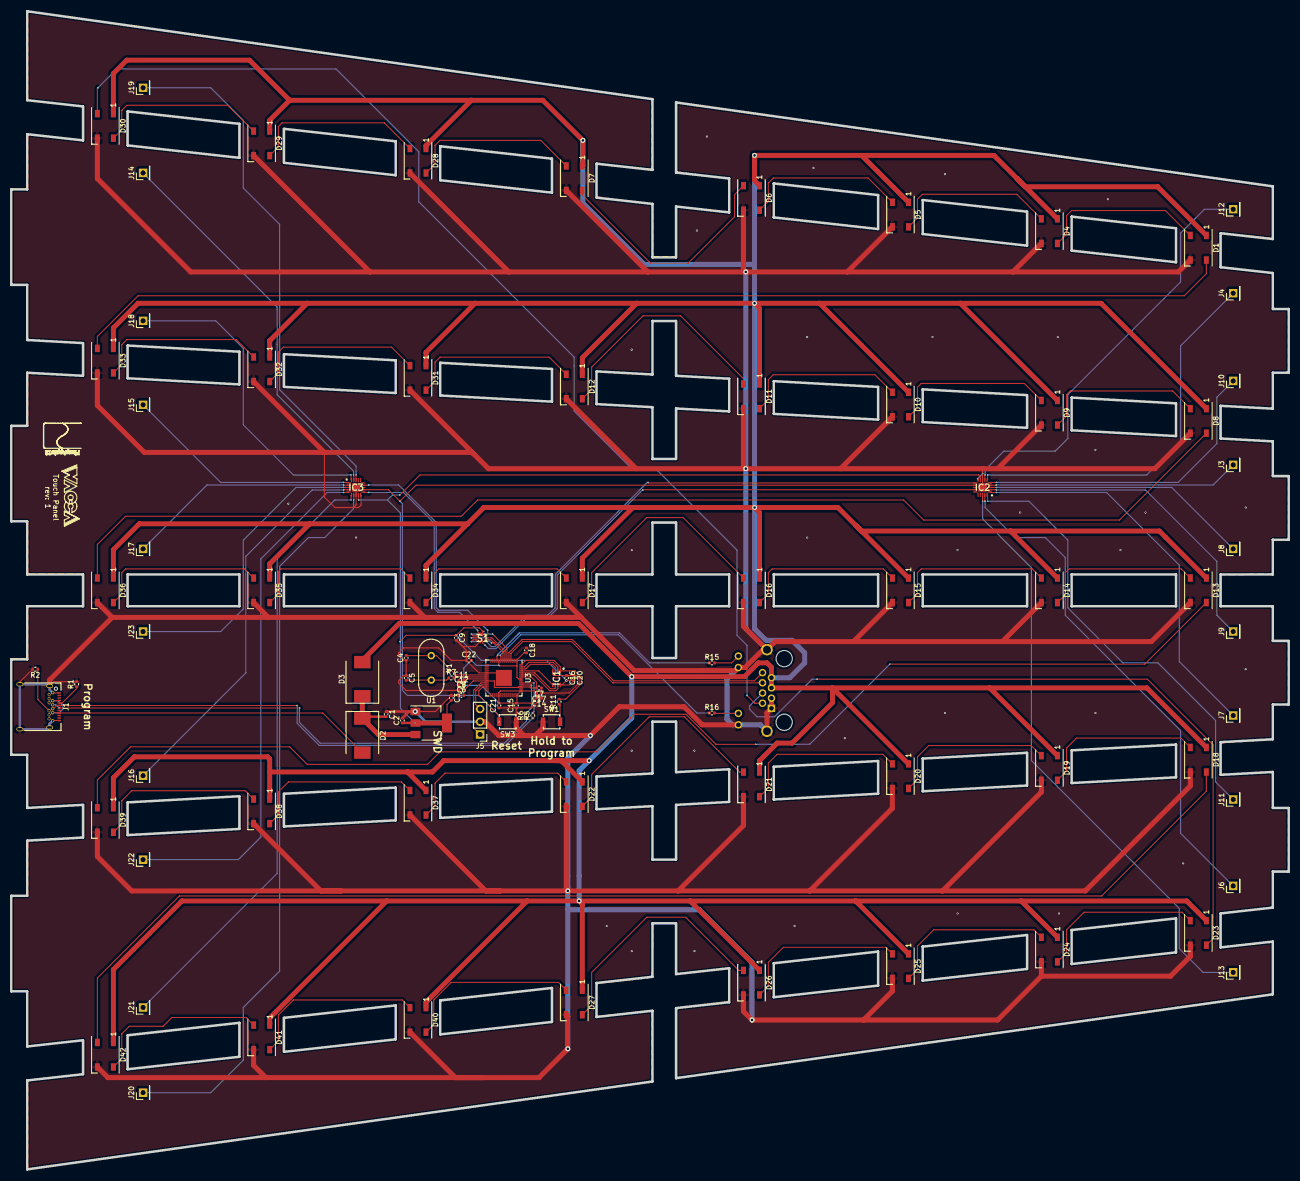
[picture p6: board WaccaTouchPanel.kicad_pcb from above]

Board: 2 copper layers, 254.9 x 231.1 mm, 101 parts (1 on the bottom side), 100 nets.

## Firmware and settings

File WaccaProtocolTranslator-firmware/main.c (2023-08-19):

#include <stdbool.h>
#include "pico/stdlib.h"
#include "hardware/i2c.h"
#include "waccaserial.h"

/*#ifdef OPT_PRESETPANELS // for autocompile
    #if OPT_SINGLE_TOUCH
        #define TOUCH_PANEL_0_ADDR 0x10
        #define TOUCH_PANEL_1_ADDR 0x10 
        #define TOUCH_PANEL_2_ADDR 0x10 
        #define TOUCH_PANEL_3_ADDR 0x10 
        #define TOUCH_PANEL_4_ADDR 0x10 
        #define TOUCH_PANEL_5_ADDR 0x10 
    #else
        #define TOUCH_PANEL_0_ADDR 0x10
        #define TOUCH_PANEL_1_ADDR 0x11 
        #define TOUCH_PANEL_2_ADDR 0x12 
        #define TOUCH_PANEL_3_ADDR 0x13 
        #define TOUCH_PANEL_4_ADDR 0x14 
        #define TOUCH_PANEL_5_ADDR 0x15 
    #endif
#endif*/

#define TOUCH_I2C_PORT i2c1
#define TOUCH_I2C_SDA 2
#define TOUCH_I2C_SCL 3
#ifndef OPT_PRESETPANELS
    #define TOUCH_PANEL_0_ADDR 0x10
    #define TOUCH_PANEL_1_ADDR 0x10 //0x11
    #define TOUCH_PANEL_2_ADDR 0x10 //0x12
    #define TOUCH_PANEL_3_ADDR 0x10 //0x13
    #define TOUCH_PANEL_4_ADDR 0x10 //0x14
    #define TOUCH_PANEL_5_ADDR 0x10 //0x15
#endif
#define TOUCH_I2C_FREQ 100000

#define TOUCH_PANEL_0_LEFT_LED 5
#define TOUCH_PANEL_0_RIGHT_LED 4
#define TOUCH_PANEL_1_LEFT_LED 7
#define TOUCH_PANEL_1_RIGHT_LED 6
#define TOUCH_PANEL_2_LEFT_LED 9
#define TOUCH_PANEL_2_RIGHT_LED 8
#define TOUCH_PANEL_3_LEFT_LED 11
#define TOUCH_PANEL_3_RIGHT_LED 10
#define TOUCH_PANEL_4_LEFT_LED 13
#define TOUCH_PANEL_4_RIGHT_LED 12
#define TOUCH_PANEL_5_LEFT_LED 15
#define TOUCH_PANEL_5_RIGHT_LED 14

uint32_t touchPanel0Data = 0;
uint32_t touchPanel1Data = 0;
uint32_t touchPanel2Data = 0;
uint32_t touchPanel3Data = 0;
uint32_t touchPanel4Data = 0;
uint32_t touchPanel5Data = 0;


uint32_t getTouchPacket(i2c_inst_t *port, uint8_t addr) {
    int bytesRead = 0;
    uint8_t data[4];

    bytesRead = i2c_read_blocking(port, addr, data, 4, false);

    if (bytesRead != 4) return 0;

    return (uint32_t) (data[0] | (data[1] << 8) | (data[2] << 16) | (data[3] << 24)); 
}

#define PingWaccaPanel(ADDR, final) do { final = getTouchPacket(TOUCH_I2C_PORT, ADDR); } while (final == 0)

void setupTouchPanels() {
    i2c_init(TOUCH_I2C_PORT, TOUCH_I2C_FREQ);

    gpio_set_function(TOUCH_I2C_SDA, GPIO_FUNC_I2C);
    gpio_set_function(TOUCH_I2C_SCL, GPIO_FUNC_I2C);

    gpio_pull_up(TOUCH_I2C_SDA);
    gpio_pull_up(TOUCH_I2C_SCL);

    gpio_init(TOUCH_PANEL_0_LEFT_LED); gpio_set_dir(TOUCH_PANEL_0_LEFT_LED, GPIO_OUT);
    gpio_init(TOUCH_PANEL_0_RIGHT_LED); gpio_set_dir(TOUCH_PANEL_0_RIGHT_LED, GPIO_OUT);
    gpio_init(TOUCH_PANEL_1_LEFT_LED); gpio_set_dir(TOUCH_PANEL_1_LEFT_LED, GPIO_OUT);
    gpio_init(TOUCH_PANEL_1_RIGHT_LED); gpio_set_dir(TOUCH_PANEL_1_RIGHT_LED, GPIO_OUT);
    gpio_init(TOUCH_PANEL_2_LEFT_LED); gpio_set_dir(TOUCH_PANEL_2_LEFT_LED, GPIO_OUT);
    gpio_init(TOUCH_PANEL_2_RIGHT_LED); gpio_set_dir(TOUCH_PANEL_2_RIGHT_LED, GPIO_OUT);
    gpio_init(TOUCH_PANEL_3_LEFT_LED); gpio_set_dir(TOUCH_PANEL_3_LEFT_LED, GPIO_OUT);
    gpio_init(TOUCH_PANEL_3_RIGHT_LED); gpio_set_dir(TOUCH_PANEL_3_RIGHT_LED, GPIO_OUT);
    gpio_init(TOUCH_PANEL_4_LEFT_LED); gpio_set_dir(TOUCH_PANEL_4_LEFT_LED, GPIO_OUT);
    gpio_init(TOUCH_PANEL_4_RIGHT_LED); gpio_set_dir(TOUCH_PANEL_4_RIGHT_LED, GPIO_OUT);
    gpio_init(TOUCH_PANEL_5_LEFT_LED); gpio_set_dir(TOUCH_PANEL_5_LEFT_LED, GPIO_OUT);
    gpio_init(TOUCH_PANEL_5_RIGHT_LED); gpio_set_dir(TOUCH_PANEL_5_RIGHT_LED, GPIO_OUT);

    gpio_put(TOUCH_PANEL_0_LEFT_LED, true);
    gpio_put(TOUCH_PANEL_1_LEFT_LED, true);
    gpio_put(TOUCH_PANEL_2_LEFT_LED, true);
    gpio_put(TOUCH_PANEL_3_LEFT_LED, true);
    gpio_put(TOUCH_PANEL_4_LEFT_LED, true);
    gpio_put(TOUCH_PANEL_5_LEFT_LED, true);

    PingWaccaPanel(TOUCH_PANEL_0_ADDR, touchPanel0Data);
    gpio_put(TOUCH_PANEL_0_LEFT_LED, false);

    PingWaccaPanel(TOUCH_PANEL_1_ADDR, touchPanel1Data);
    gpio_put(TOUCH_PANEL_1_LEFT_LED, false);

    PingWaccaPanel(TOUCH_PANEL_2_ADDR, touchPanel2Data);
    gpio_put(TOUCH_PANEL_2_LEFT_LED, false);

    PingWaccaPanel(TOUCH_PANEL_3_ADDR, touchPanel3Data);
    gpio_put(TOUCH_PANEL_3_LEFT_LED, false);

    PingWaccaPanel(TOUCH_PANEL_4_ADDR, touchPanel4Data);
    gpio_put(TOUCH_PANEL_4_LEFT_LED, false);
    
    PingWaccaPanel(TOUCH_PANEL_5_ADDR, touchPanel5Data);
    gpio_put(TOUCH_PANEL_5_LEFT_LED, false);

    ws_setTouchData(touchPanel0Data, touchPanel1Data, touchPanel2Data, touchPanel3Data, touchPanel4Data, touchPanel5Data);
}

int main() {
    ws_start();

    setupTouchPanels();

    gpio_put(TOUCH_PANEL_0_RIGHT_LED, true);
    gpio_put(TOUCH_PANEL_1_RIGHT_LED, true);
    gpio_put(TOUCH_PANEL_2_RIGHT_LED, true);
    gpio_put(TOUCH_PANEL_3_RIGHT_LED, true);
    gpio_put(TOUCH_PANEL_4_RIGHT_LED, true);
    gpio_put(TOUCH_PANEL_5_RIGHT_LED, true);

    while(1) { // note: getting a touch packet might take a bit, use this rolling update to speed up input throughput to the game
        gpio_put(TOUCH_PANEL_0_LEFT_LED, true);
        touchPanel0Data = getTouchPacket(TOUCH_I2C_PORT, TOUCH_PANEL_0_ADDR);
        ws_setTouch0Data(touchPanel0Data);
        gpio_put(TOUCH_PANEL_0_LEFT_LED, false);

        gpio_put(TOUCH_PANEL_1_LEFT_LED, true);
        touchPanel1Data = getTouchPacket(TOUCH_I2C_PORT, TOUCH_PANEL_1_ADDR);
        ws_setTouch1Data(touchPanel1Data);
        gpio_put(TOUCH_PANEL_1_LEFT_LED, false);

        gpio_put(TOUCH_PANEL_2_LEFT_LED, true);
        touchPanel2Data = getTouchPacket(TOUCH_I2C_PORT, TOUCH_PANEL_2_ADDR);
        ws_setTouch2Data(touchPanel2Data);
        gpio_put(TOUCH_PANEL_2_LEFT_LED, false);

        gpio_put(TOUCH_PANEL_3_LEFT_LED, true);
        touchPanel3Data = getTouchPacket(TOUCH_I2C_PORT, TOUCH_PANEL_3_ADDR);
        ws_setTouch3Data(touchPanel3Data);
        gpio_put(TOUCH_PANEL_3_LEFT_LED, false);

        gpio_put(TOUCH_PANEL_4_LEFT_LED, true);
        touchPanel4Data = getTouchPacket(TOUCH_I2C_PORT, TOUCH_PANEL_4_ADDR);
        ws_setTouch4Data(touchPanel4Data);
        gpio_put(TOUCH_PANEL_4_LEFT_LED, false);

        gpio_put(TOUCH_PANEL_5_LEFT_LED, true);
        touchPanel5Data = getTouchPacket(TOUCH_I2C_PORT, TOUCH_PANEL_5_ADDR);
        ws_setTouch5Data(touchPanel5Data);
        gpio_put(TOUCH_PANEL_5_LEFT_LED, false);
    }

    return 0;
}

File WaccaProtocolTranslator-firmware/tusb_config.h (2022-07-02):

#ifndef _TUSB_CONFIG_H_
#define _TUSB_CONFIG_H_

//--------------------------------------------------------------------
// COMMON CONFIGURATION
//--------------------------------------------------------------------

// defined by board.mk
#ifndef CFG_TUSB_MCU
  #error CFG_TUSB_MCU must be defined
#endif

// RHPort number used for device can be defined by board.mk, default to port 0
#ifndef BOARD_DEVICE_RHPORT_NUM
  #define BOARD_DEVICE_RHPORT_NUM     0
#endif

#define BOARD_DEVICE_RHPORT_SPEED   OPT_MODE_FULL_SPEED

// Device mode with rhport and speed defined by board.mk
#if   BOARD_DEVICE_RHPORT_NUM == 0
  #define CFG_TUSB_RHPORT0_MODE     (OPT_MODE_DEVICE | BOARD_DEVICE_RHPORT_SPEED)
#elif BOARD_DEVICE_RHPORT_NUM == 1
  #define CFG_TUSB_RHPORT1_MODE     (OPT_MODE_DEVICE | BOARD_DEVICE_RHPORT_SPEED)
#else
  #error "Incorrect RHPort configuration"
#endif

#ifndef CFG_TUSB_OS
#define CFG_TUSB_OS                 OPT_OS_NONE
#endif

#ifndef CFG_TUSB_MEM_SECTION
#define CFG_TUSB_MEM_SECTION
#endif

#ifndef CFG_TUSB_MEM_ALIGN
#define CFG_TUSB_MEM_ALIGN          __attribute__ ((aligned(4)))
#endif

//--------------------------------------------------------------------
// DEVICE CONFIGURATION
//--------------------------------------------------------------------

#ifndef CFG_TUD_ENDPOINT0_SIZE
#define CFG_TUD_ENDPOINT0_SIZE    64
#endif

#define CFG_TUD_CDC               1
#define CFG_TUD_MSC               0
#define CFG_TUD_HID               0
#define CFG_TUD_MIDI              0
#define CFG_TUD_VENDOR            0

#define CFG_TUD_CDC_RX_BUFSIZE   (TUD_OPT_HIGH_SPEED ? 512 : 64)
#define CFG_TUD_CDC_TX_BUFSIZE   (TUD_OPT_HIGH_SPEED ? 512 : 64)

#define CFG_TUD_CDC_EP_BUFSIZE   (TUD_OPT_HIGH_SPEED ? 512 : 64)

#endif /* _TUSB_CONFIG_H_ */

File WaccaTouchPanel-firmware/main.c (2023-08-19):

#include <stdio.h>
#include <stdbool.h>
#include "pico/stdlib.h"
#include "hardware/i2c.h"
#include "hardware/irq.h"
#include "mpr121.h"

//#define DEBUG_MODE // uncomment for debug messages (note: this will slow things down!)

#if OPT_PANEL1 // used for automatic compilation
    #define MOTHERBOARD_I2C_HWID 0x10
#elif OPT_PANEL2
    #define MOTHERBOARD_I2C_HWID 0x11
#elif OPT_PANEL3
    #define MOTHERBOARD_I2C_HWID 0x12
#elif OPT_PANEL4
    #define MOTHERBOARD_I2C_HWID 0x13
#elif OPT_PANEL5
    #define MOTHERBOARD_I2C_HWID 0x14
#elif OPT_PANEL6
    #define MOTHERBOARD_I2C_HWID 0x15
#endif

#define MOTHERBOARD_I2C_PORT i2c1
#define MOTHERBOARD_I2C_IRQ I2C1_IRQ
#ifndef MOTHERBOARD_I2C_HWID
    #define MOTHERBOARD_I2C_HWID 0x10 // 0x1[0-5 depending on which position it's in bottom to top]
#endif
#define MOTHERBOARD_I2C_SDA 2
#define MOTHERBOARD_I2C_SCL 3
#define MOTHERBOARD_I2C_FREQ 100000

#define TOUCH_I2C_PORT i2c0
#define TOUCH_I2C_SDA 4
#define TOUCH_I2C_SCL 5
#define INNER_MPR121_ADDR 0x5A
#define OUTER_MPR121_ADDR 0x5B
#define TOUCH_I2C_FREQ 100000
#define MPR121_TOUCH_THRESHOLD 16
#define MPR121_RELEASE_THRESHOLD 10

// Buttons
// [--] [--] [--] [--] [--]
// [--] [--] [--] [--] [--]
// [--] [--] [  ] [  ] [  ]
// [  ] [  ] [  ] [  ] [  ]

struct mpr121_sensor innerSensor;
uint16_t touchedInner = 0;

// Buttons
// [  ] [  ] [  ] [  ] [  ]
// [  ] [  ] [  ] [  ] [  ]
// [  ] [  ] [--] [--] [--]
// [--] [--] [--] [--] [--]

struct mpr121_sensor outerSensor;
uint16_t touchedOuter = 0;

// Button bits
// [ 0] [ 1] [ 2] [ 3] [ 4]
// [ 5] [ 6] [ 7] [ 8] [ 9]
// [10] [11] [12] [13] [14]
// [15] [16] [17] [18] [19]

uint32_t previousTouchDataPacket = 0;
bool writingPacket = false;
uint32_t touchDataPacket = 0;

uint8_t byteSelector = 0;

#define txByte(i2c, byte) while (!i2c_get_write_available(i2c)) { ; } i2c->hw->data_cmd = byte

void i2cSlaveI2CIRQHandler() {
    uint32_t status = MOTHERBOARD_I2C_PORT->hw->intr_stat;

    if (status & I2C_IC_INTR_STAT_R_RD_REQ_BITS) {
        uint32_t dataToSend = previousTouchDataPacket;

        if (!writingPacket) dataToSend = touchDataPacket;

        #ifdef DEBUG_MODE
            printf("Master requested packet, sending [%u %u %u %u]...\n", (uint8_t) (dataToSend), (uint8_t) (dataToSend >> 8), (uint8_t) (dataToSend >> 16), (uint8_t) (dataToSend >> 24));
        #endif

        gpio_put(PICO_DEFAULT_LED_PIN, true);

        txByte(MOTHERBOARD_I2C_PORT, (uint8_t) (dataToSend));
        txByte(MOTHERBOARD_I2C_PORT, (uint8_t) (dataToSend >> 8));
        txByte(MOTHERBOARD_I2C_PORT, (uint8_t) (dataToSend >> 16));
        txByte(MOTHERBOARD_I2C_PORT, (uint8_t) (dataToSend >> 24));

        MOTHERBOARD_I2C_PORT->hw->clr_rd_req;

        gpio_put(PICO_DEFAULT_LED_PIN, false);
    }
}



void setupTouch() {
    i2c_init(TOUCH_I2C_PORT, TOUCH_I2C_FREQ);

    gpio_set_function(TOUCH_I2C_SDA, GPIO_FUNC_I2C);
    gpio_set_function(TOUCH_I2C_SCL, GPIO_FUNC_I2C);

    gpio_pull_up(TOUCH_I2C_SDA);
    gpio_pull_up(TOUCH_I2C_SCL);

    mpr121_init(TOUCH_I2C_PORT, INNER_MPR121_ADDR, &innerSensor);
    mpr121_set_thresholds(MPR121_TOUCH_THRESHOLD, MPR121_RELEASE_THRESHOLD, &innerSensor);

    mpr121_init(TOUCH_I2C_PORT, OUTER_MPR121_ADDR, &outerSensor);
    mpr121_set_thresholds(MPR121_TOUCH_THRESHOLD, MPR121_RELEASE_THRESHOLD, &outerSensor);

    
    gpio_init(PICO_DEFAULT_LED_PIN);
    gpio_set_dir(PICO_DEFAULT_LED_PIN, GPIO_OUT);
}

void setupMotherboard() {
    i2c_init(MOTHERBOARD_I2C_PORT, MOTHERBOARD_I2C_FREQ);
    i2c_set_slave_mode(MOTHERBOARD_I2C_PORT, true, MOTHERBOARD_I2C_HWID);

    MOTHERBOARD_I2C_PORT->hw->enable = 0;
    hw_set_bits(&MOTHERBOARD_I2C_PORT->hw->con, I2C_IC_CON_RX_FIFO_FULL_HLD_CTRL_BITS);
    MOTHERBOARD_I2C_PORT->hw->enable = 1;

    gpio_set_function(MOTHERBOARD_I2C_SDA, GPIO_FUNC_I2C);
    gpio_set_function(MOTHERBOARD_I2C_SCL, GPIO_FUNC_I2C);
    gpio_pull_up(MOTHERBOARD_I2C_SDA);
    gpio_pull_up(MOTHERBOARD_I2C_SCL);

    MOTHERBOARD_I2C_PORT->hw->intr_mask = I2C_IC_INTR_MASK_M_RD_REQ_BITS;//(I2C_IC_INTR_MASK_M_RD_REQ_BITS | I2C_IC_INTR_MASK_M_RX_FULL_BITS);

    irq_set_exclusive_handler(MOTHERBOARD_I2C_IRQ, i2cSlaveI2CIRQHandler);

    irq_set_enabled(MOTHERBOARD_I2C_IRQ, true);
}

#ifdef DEBUG_MODE
    #define formatButton(data, number) (((data) & (1 << (number))) ? "#" : " ")
    #define printMultiButtonRow(data1, data2, n1, n2, n3, n4, n5) printf("[%s] [%s] [%s] [%s] [%s]\n", formatButton(data1, n1), formatButton(data1, n2), formatButton(data2, n3), formatButton(data2, n4), formatButton(data2, n5))
    #define printButtonRow(data, n1, n2, n3, n4, n5) printf("[%s] [%s] [%s] [%s] [%s]\n", formatButton(data, n1), formatButton(data, n2), formatButton(data, n3), formatButton(data, n4), formatButton(data, n5))
#endif

int main() {
    //stdio_init_all();
    printf("Wacca Touch Panel v0.1\n");

    printf("Setting up Touch...");
    setupTouch();
    printf("OK\n");

    printf("Setting up Communications...");
    setupMotherboard();
    printf("OK\n");

    while(true) {
        mpr121_touched(&touchedInner, &innerSensor);
        mpr121_touched(&touchedOuter, &outerSensor);

        touchedInner = touchedInner & 0b0000111111111111;
        touchedOuter = touchedOuter & 0b0000000011111111;

        writingPacket = true;

        touchDataPacket = (((uint32_t) touchedOuter << 12) | touchedInner) | 0x69000000;

        #ifdef DEBUG_MODE
            printf("-------------------\n");
            printButtonRow(touchedInner, 0, 1, 2, 3, 4);
            printButtonRow(touchedInner, 5, 6, 7, 8, 9);
            printMultiButtonRow(touchedInner, touchedOuter, 10, 11, 0, 1, 2);
            printButtonRow(touchedOuter, 3, 4, 5, 6, 7);
            printf("-------------------\n");
        #endif

        writingPacket = false;

        sleep_ms(10);
    }

    return 0;
}

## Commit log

2022-07-01 Initial commit with V1 hardware
    [Full Controller.iam, Half Ring.iam, Touch Casing.ipt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]
2022-07-01 Hardware V2
    [Full Controller.iam, Half Ring.iam, Touch Casing.ipt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]
2022-07-01 Hardware V3
    [Back Plate.ipt, Center Plate.ipt, Front Plate.ipt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]
2022-07-02 it's alive! still need to add some serial port and i2c init fixes but other than that this is pretty much ready to go.
    [main.c, waccaserial.c]
2022-07-02 replaced the default pico uart libs with a custom tinyusb-based serial lib
    [main.c, tusb_config.h, waccaserial.c]
2022-07-03 got to work on the schematic for the Protocol Translator, it's unfinished though
    [WaccaProtocolTranslator.kicad_pcb, WaccaProtocolTranslator.kicad_sch, WaccaProtocolTranslator.sch]
2022-07-05 designed the Protocol Translator PCB and added a PCB build task during production file generation
    [WaccaProtocolTranslator.kicad_pcb, WaccaProtocolTranslator.kicad_sch]
2022-07-05 added cad generation and changed the an artifact name for clarity
2022-07-05 forgot to add cad config
2022-07-07 Got a ton of work done on the Touch Panel PCB, still need to route the LED traces
    [Back Plate.ipt, Center Plate.ipt, Front Plate.ipt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]
2022-07-07 finished Touch Panel PCB and added it to actions
    [Center Plate.ipt, Full Controller.iam, Half Ring.iam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]
2023-08-19 A few changes that needed to be pushed, the power switching circuitry has been removed temporarily to allow for manual power switching. I also baked the FT232HQ connection to the LED bus and changed 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
    [Back Plate.ipt, Center Plate.ipt, Front Plate.ipt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]
2023-08-19 update kibot to kicad 7
2023-08-19 attempt 2 to fix the pcbdraw style path
